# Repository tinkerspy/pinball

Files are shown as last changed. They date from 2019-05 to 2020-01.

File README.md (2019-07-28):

# Automaton Pinball

Pinball programming framework being built on a 1973 Williams OXO pinball machine.

- Modular cat5 cable connected architecture with just a single Teensy 3.2 mcu
- Three dimensional switch matrix with 5 x 8 x 8 = 320 switches
- Outputs controlled by addressable led strips (sk6812/ws2812b)
- Solenoids driven by optical mosfet switches
- Galvanic isolation between logical (5V) and power circuits (24V+)
- Event driven Automaton-framework based code

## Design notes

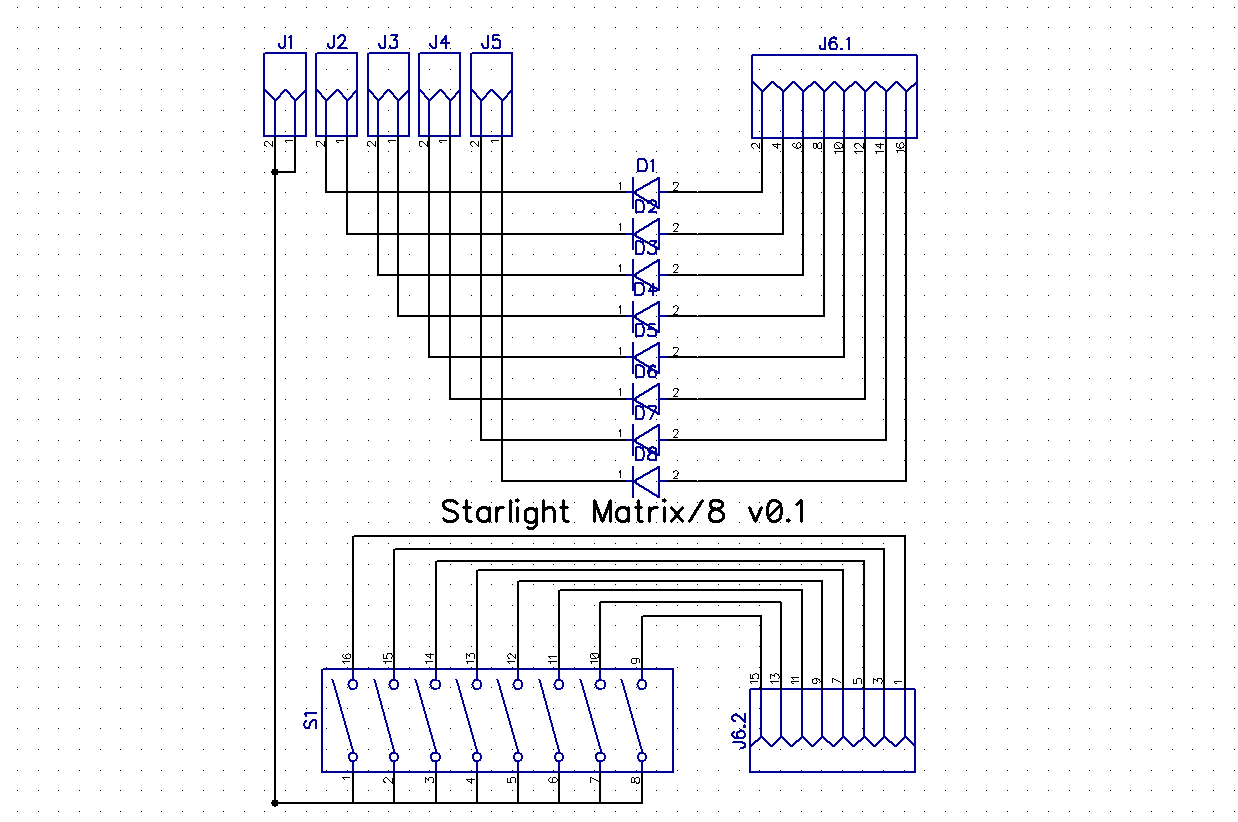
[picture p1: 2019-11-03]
diptrace/png/switchnodexl02-schematic.png

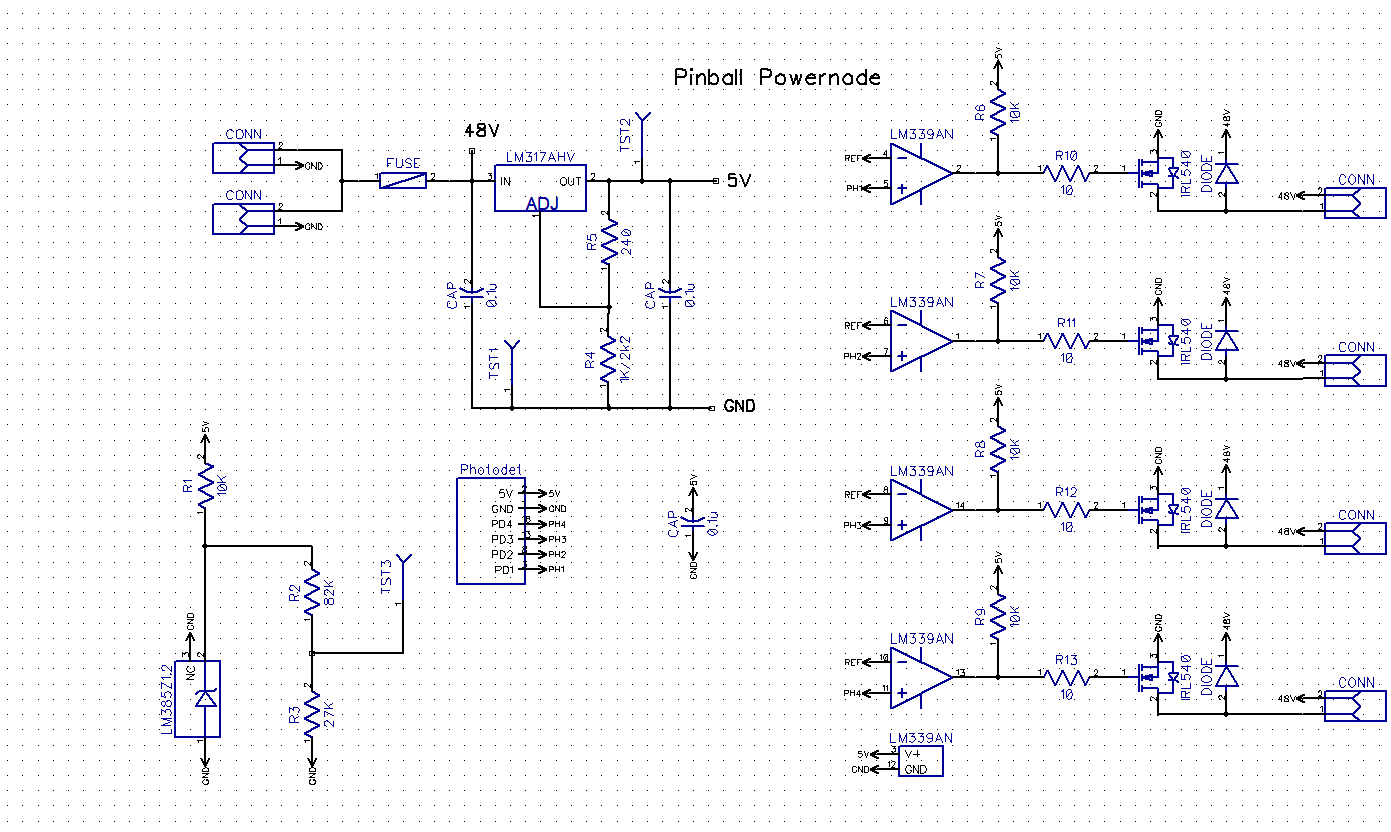
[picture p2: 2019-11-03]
diptrace/png/powernode03-schematic.png

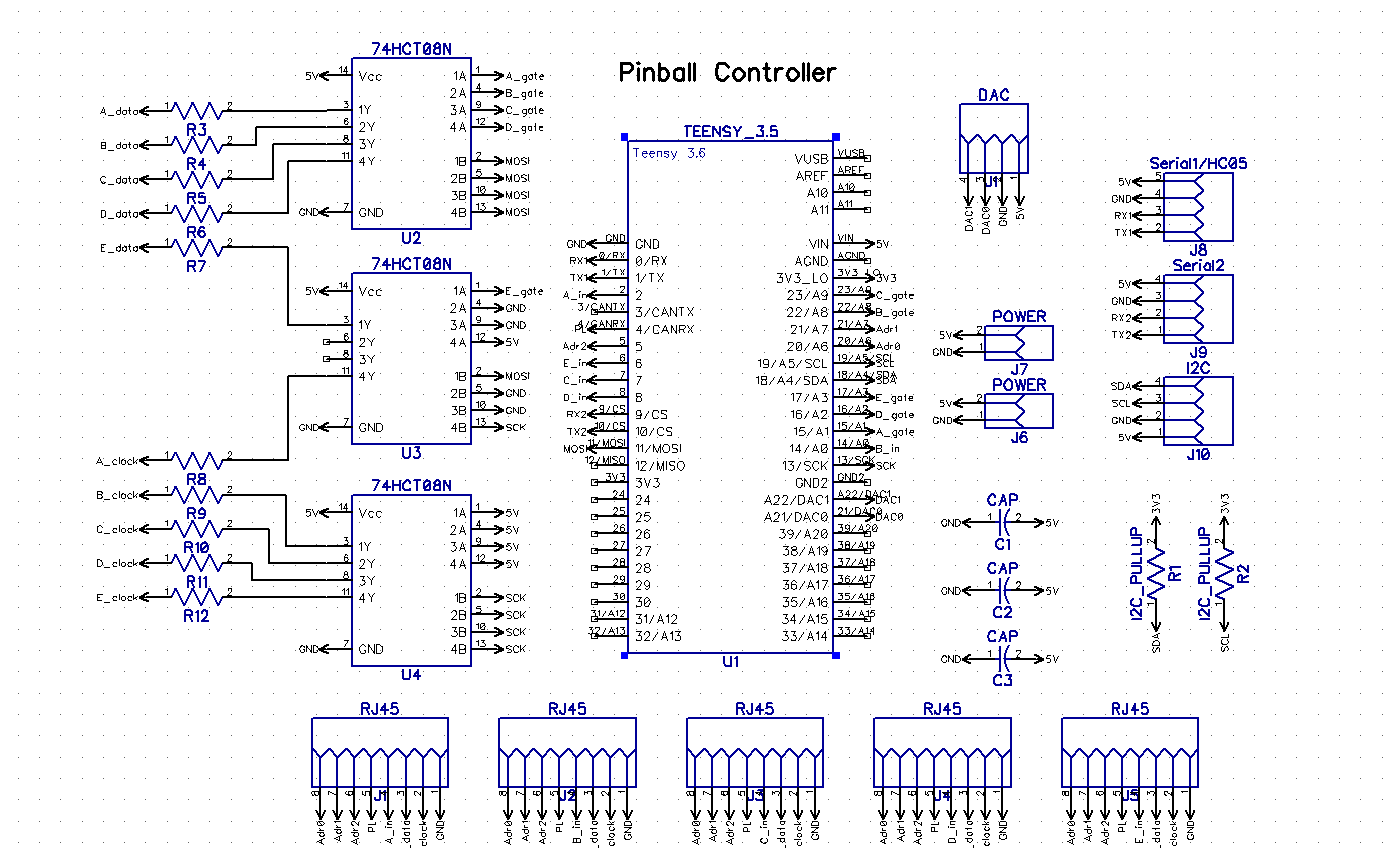
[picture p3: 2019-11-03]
diptrace/png/controller02-schematic.png

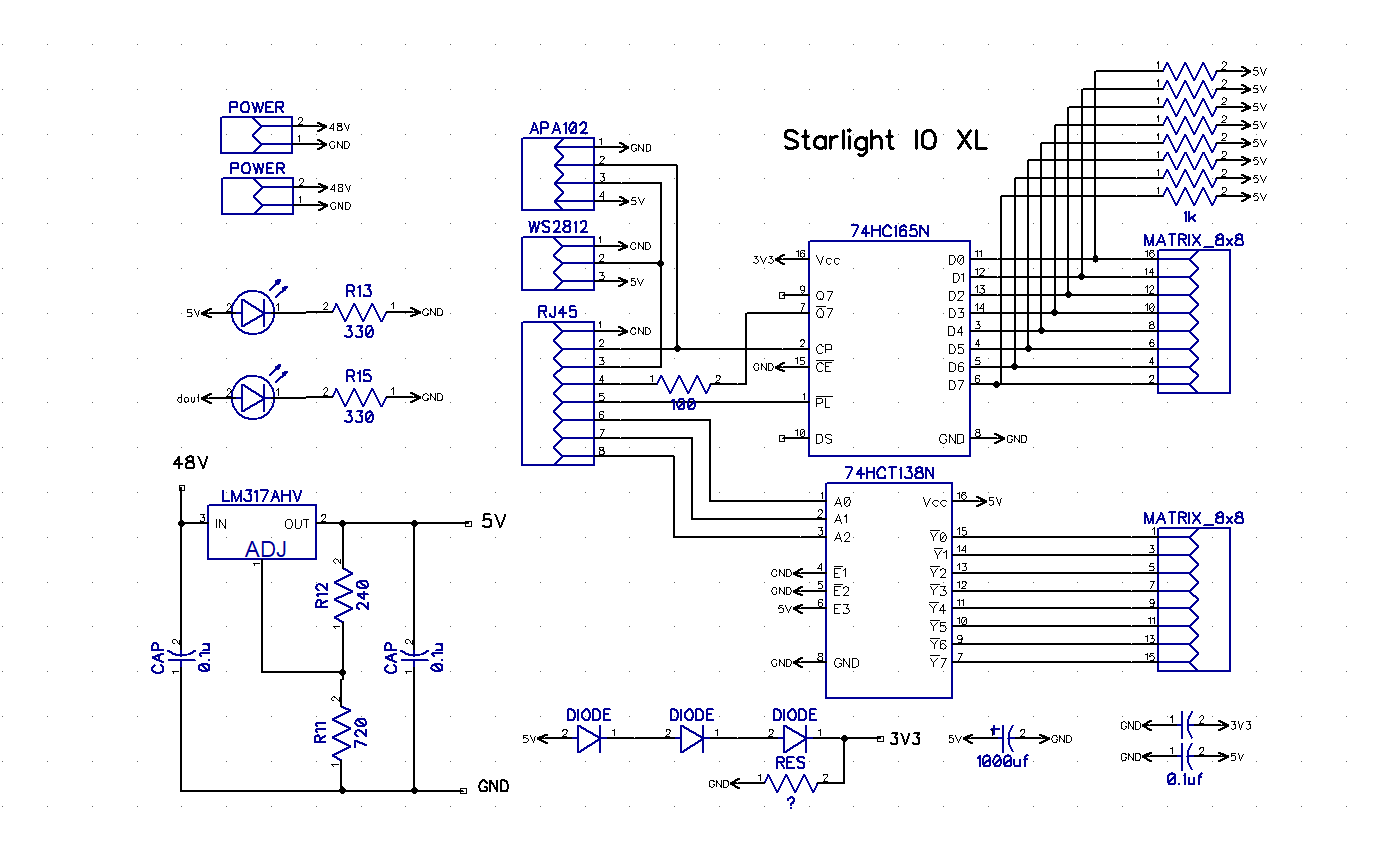
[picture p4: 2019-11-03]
diptrace/png/ionode03p-schematic.png

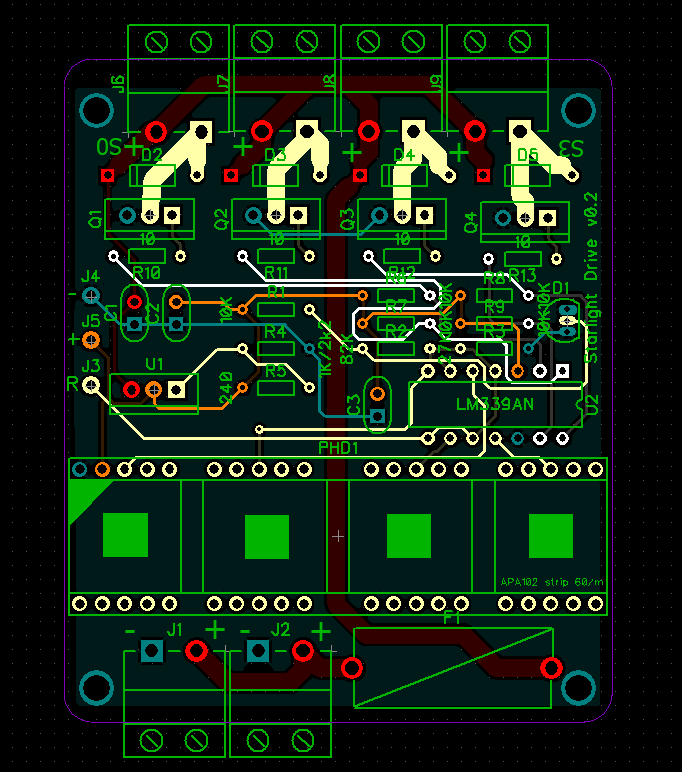
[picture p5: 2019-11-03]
diptrace/png/powernode03-pcb.png

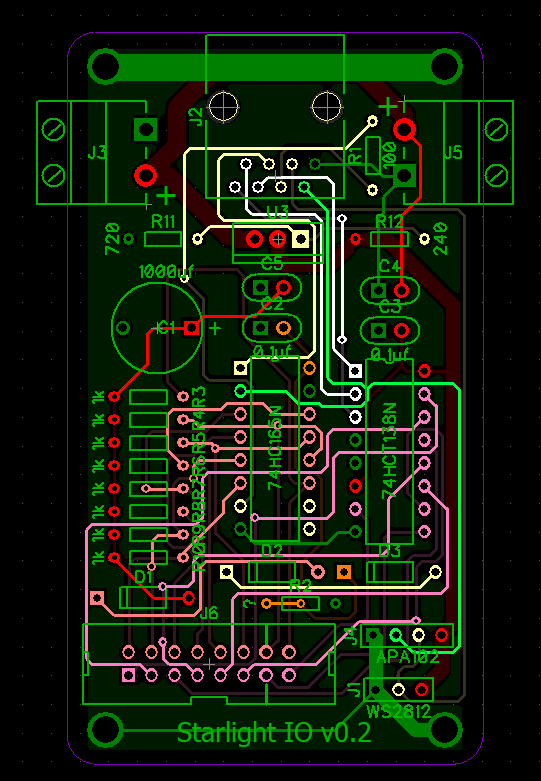
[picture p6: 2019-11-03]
diptrace/png/ionode03p-pcb.png

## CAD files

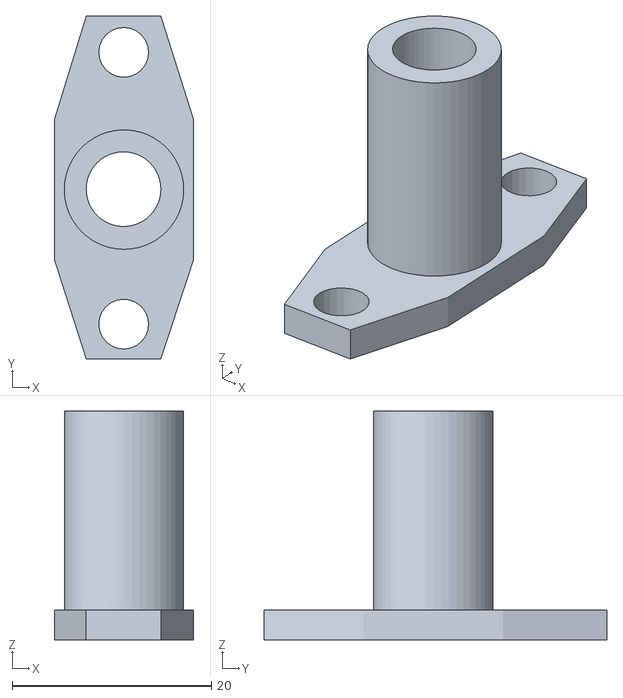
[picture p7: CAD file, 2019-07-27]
3d/pinball-led-insert.stl
14.0 x 34.4 x 23.0

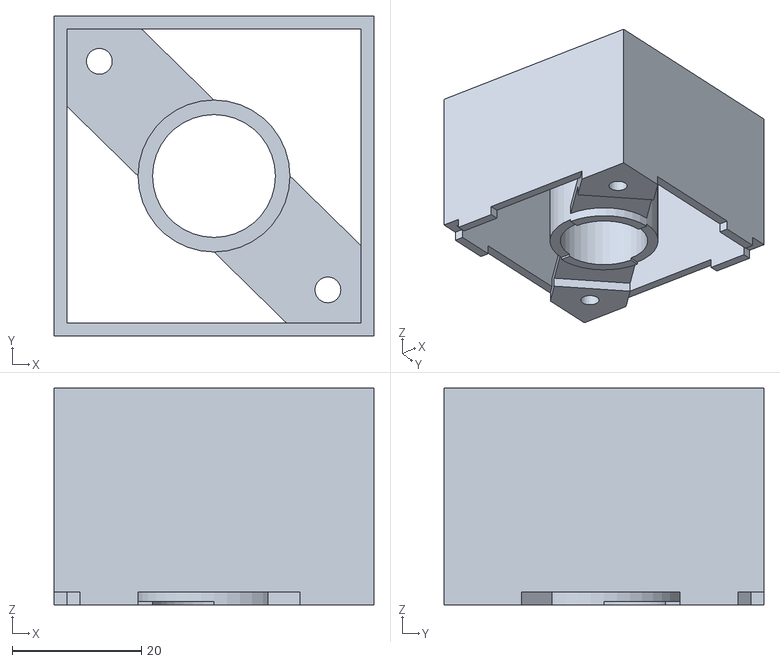
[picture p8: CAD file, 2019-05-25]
3d/oxo-insert.0.1b.stl
49.5 x 49.5 x 33.5

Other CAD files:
3d/oxo-insert.0.1.stl
3d/oxo-insert.0.1.skp
3d/oxo-insert.0.1b.skp
3d/pinball-led-insert.skp

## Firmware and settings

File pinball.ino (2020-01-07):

#include "Singularity.h"
#include "hardware.h"
#include "switches.h"
#include "leds.h"
#include "profiles.h"
#include "firmware_custom.h"
#include "freeram.hpp"

#define PRELOAD_CONFIG
#undef COMPILE_FW
#define NUMBER_OF_BALLS 3
#define NUMBER_OF_PLAYERS 4

using namespace standard_firmware;
using namespace custom_firmware; 

IO io;
Atm_led_matrix leds; 
Atm_switch_matrix playfield;
Library lib;

#include "CLI.h"

void setup() {
  delay( 100 );
  Serial.println( "Singularity Shell\r\ninit IO" );

  Serial1.begin( 9600 );
  cmd[0].begin( Serial, cmd_buffer[0], sizeof( cmd_buffer[0] ) )
    .list( cmdlist )
    .echo( true )
    .onCommand( cmd_callback, 0 );
    
  cmd[1].begin( Serial1, cmd_buffer[1], sizeof( cmd_buffer[1] ) ) 
    .list( cmdlist )
    .echo( true )
    .onCommand( cmd_callback, 1 );
    
  Serial1.println( "Singularity OS" );

  io.begin( pin_clock, pin_latch, addr, shift_inputs, gate );
  
  int32_t base_ram = FreeRam();

#ifdef COMPILE_FW
  Serial.println( "compile firmware from flash" ); //delay( 100 );
  lib.compile( "std_bumper", bumper_bytecode );
  lib.compile( "std_dual_target", dual_target_bytecode );
  lib.compile( "std_counter_em4d1w", counter_em4d1w_bytecode );
  lib.compile( "std_ledbank", ledbank_bytecode );
  lib.compile( "std_switchbank", switchbank_bytecode );
  lib.compile( "std_scalar", scalar_bytecode );
  lib.compile( "std_dual_kicker", dual_kicker_bytecode  );
  lib.compile( "std_dual_slingshot", dual_slingshot_bytecode  );
  lib.compile( "std_dual_combo", dual_combo_bytecode );
  lib.compile( "std_dual_flipper", dual_flipper_bytecode );

  lib.compile( "std_game", game_bytecode );
  lib.compile( "std_tictactoe", tictactoe_bytecode ); // phucked! it's just too big for loadintlist!!!
  lib.compile( "std_animation", animation_bytecode );
#else 
  Serial.println( "import firmware from flash" ); //delay( 100 );
  lib.import( "std_bumper", std_bumper_symbin, std_bumper_hexbin );
  lib.import( "std_dual_target", std_dual_target_symbin, std_dual_target_hexbin );
  lib.import( "std_counter_em4d1w", std_counter_em4d1w_symbin, std_counter_em4d1w_hexbin );
  lib.import( "std_ledbank", std_ledbank_symbin, std_ledbank_hexbin );
  lib.import( "std_switchbank", std_switchbank_symbin, std_switchbank_hexbin );
  lib.import( "std_scalar", std_scalar_symbin, std_scalar_hexbin );
  lib.import( "std_dual_kicker", std_dual_kicker_symbin, std_dual_kicker_hexbin  );
  lib.import( "std_dual_slingshot", std_dual_slingshot_symbin, std_dual_slingshot_hexbin  );
  lib.import( "std_dual_combo", std_dual_combo_symbin, std_dual_combo_hexbin );
  lib.import( "std_dual_flipper", std_dual_flipper_symbin, std_dual_flipper_hexbin );
  
  lib.import( "std_game", std_game_symbin, std_game_hexbin );
  lib.import( "std_tictactoe", std_tictactoe_symbin, std_tictactoe_hexbin );
  lib.import( "std_animation", std_animation_symbin, std_animation_hexbin );
#endif


#ifdef PRELOAD_CONFIG
  #include "load_config.h"
#endif

//  playfield.device( "kicker" ).trigger( IN_KICKER_PERSIST ); FIXME SOMEHOW!
  
  Serial.printf( "%.2f KBytes available, %.2f KBytes used for devices, %.2f Bytes free\r\n\r\n", 
        (float) base_ram / 1024, (float)( base_ram - FreeRam() ) / 1024, (float)( FreeRam() ) );

}

void loop() {
  automaton.run(); 
}

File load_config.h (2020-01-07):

  io.attach( 0, 3, new IO_Adafruit_NeoPixel( 53, pin_data, IO_Adafruit_NeoPixel::str2int( "neo_grbw" ) + IO_Adafruit_NeoPixel::str2int( "neo_khz800" ) ) );
  io.attach( 1, 1, new IO_Adafruit_NeoPixel( 12, pin_data, IO_Adafruit_NeoPixel::str2int( "neo_grbw" ) + IO_Adafruit_NeoPixel::str2int( "neo_khz800" ) ) );
  io.attach( 2, 1, new IO_Adafruit_NeoPixel( 36, pin_data, IO_Adafruit_NeoPixel::str2int( "neo_grbw" ) + IO_Adafruit_NeoPixel::str2int( "neo_khz800" ) ) );
  io.retrigger();
  io.show();

  leds.begin( io );
  playfield.begin( io, leds );

  leds.loadSymbols( led_symbols );
  leds.loadGroups( led_group_list  );

  playfield.loadSymbols( switch_symbols );
  playfield.loadGroups( switch_group_list );

  io.invert( playfield.findSymbol( "ball_enter" ) );

  Serial.println( "led profiles" ); //delay( 100 );

  //                                   T0,  L1,  T1,  L2  
  leds.profile( "led_kicker_l"     ,    0,   0,   0, 127 );
  leds.profile( "led_kicker_r"     ,    0,   0,   0, 127 );
  leds.profile( "led_target_grp"   ,    0,   0,   0, 127 );
  leds.profile( "led_uplane_grp"   ,    0,   0,   0, 127 );
  leds.profile( "led_bumper_a"     ,    0,   0,   0, 127 );
  leds.profile( "led_bumper_b"     ,    0,   0,   0, 127 );
  leds.profile( "led_bumper_c"     ,    0,   0,   0, 127 );
  leds.profile( "led_again0"       ,    0,   0,   0, 127 );
  leds.profile( "led_triple_bonus" ,    0,   0,   0, 127 );
  leds.profile( "led_extra"        ,    0,   0,   0, 127 );
  leds.profile( "led_headbox_grp"  ,    0,   0,   0, 255 );
  leds.profile( "led_oxo_grp"      ,    0,   0,   0, 127 );
  leds.profile( "coil_gi"          ,    0,   0,   0, 255 );
  leds.profile( "coil_sling_r"     ,    0, 255,  30,   0 );
  leds.profile( "coil_sling_l"     ,    0, 255,  30,   0 );
  leds.profile( "coil_flipper_l"   ,    0,   0,   0, 255 );
  leds.profile( "coil_flipper_r"   ,    0,   0,   0, 255 );
  leds.profile( "coil_kicker_r"    , 1000,  95,  30,   0 );
  leds.profile( "coil_kicker_l"    , 1000,  95,  30,   0 );
  leds.profile( "coil_save_gate"   ,    0,   0,   0, 255 );
  leds.profile( "coil_bumper_a"    ,    0, 255,  40,   0 );
  leds.profile( "coil_bumper_b"    ,    0, 255,  40,   0 );
  leds.profile( "coil_bumper_c"    ,    0, 255,  40,   0 );
  leds.profile( "coil_feeder"      ,    0, 127,  30,   0 );
  leds.profile( "coil_counter_grp" ,    0, 180,  20,   0 );
  leds.profile( "vled_counter0"    ,    0,   0,   0, 127 );
  leds.profile( "vled_counter1"    ,    0,   0,   0, 127 );
  leds.profile( "vled_counter2"    ,    0,   0,   0, 127 );
  leds.profile( "vled_counter3"    ,    0,   0,   0, 127 );
  leds.profile( "vled_collecting"  ,    0,   0,   0, 127 );
  leds.profile( "vled_5"           ,    0,   0,   0, 127 );
  leds.profile( "vled_6"           ,    0,   0,   0, 127 );
  leds.profile( "vled_7"           ,    0,   0,   0, 127 );
  
  Serial.println( "switch profiles" ); //delay( 100 );
  //                                    press,  rel,  thr,  sep
  playfield.profile( "switches"       ,   200,    0,    0,    0 );  // Default for switches
  playfield.profile( "multilane"      ,   200,  200,    0,    0 );
  playfield.profile( "sling_l"        ,     5,    0, 5000,    0 );  // Slingshots
  playfield.profile( "sling_r"        ,     5,    0, 5000,    0 );
  playfield.profile( "bumper_a"       ,     0,    0, 2000,    0 );  // Bumpers
  playfield.profile( "bumper_b"       ,     0,    0, 2000,    0 );
  playfield.profile( "bumper_c"       ,     0,    0, 2000,    0 );
  playfield.profile( "flipper"        ,     0,   10,    0,    0 );  // Flippers
  playfield.profile( "counter0"       ,     0,  200,    0,    0 );  // Counter sensors
  playfield.profile( "counter1"       ,     0,  200,    0,    0 );
  playfield.profile( "counter2"       ,     0,  200,    0,    0 );
  playfield.profile( "counter3"       ,     0,  200,    0,    0 );
  playfield.profile( "port_3x"        ,     5,    0, 5000,    0 );
  playfield.profile( "port_3o"        ,     5,    0, 5000,    0 );
  playfield.profile( "port_2x"        ,     5,    0, 5000,    0 );
  playfield.profile( "port_2o"        ,     5,    0, 5000,    0 );
  playfield.profile( "port_1x"        ,     5,    0, 5000,    0 );
  playfield.profile( "port_1o"        ,     5,    0, 5000,    0 );
  playfield.profile( "uplane_l"       ,     5,    0, 5000,    0 );
  playfield.profile( "uplane_r"       ,     5,    0, 5000,    0 );
  playfield.profile( "outlane"        ,     5,    0, 5000,    0 );
  playfield.profile( "inlane_l"       ,     5,    0, 5000,    0 );
  playfield.profile( "inlane_r"       ,     5,    0, 5000,    0 );
  playfield.profile( "ball_enter"     ,     5,    0, 5000,    0 );
  playfield.profile( "rollover"       ,     1,    0, 5000,    0 );
  playfield.profile( "target_a"       ,     2,    0,    0,    0 );
  playfield.profile( "target_b"       ,     2,    0,    0,    0 );
  playfield.profile( "target_c"       ,     2,    0,    0,    0 );
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

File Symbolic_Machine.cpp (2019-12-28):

#include "Symbolic_Machine.hpp"

void Symbolic_Machine::clearComments( char s[] ) {
  char* p = s;
  bool comment = 0;
  while ( *p != '\0' ) {
     if ( *p == '/' ) comment = 1;
     if ( *p == '\n' ) comment = 0;
     if ( comment ) *p = ' ';
     p++; 
  }
}

int16_t Symbolic_Machine::loadIntList( const symbolic_machine_table* symbols, const char src[], int16_t dst[], int16_t dict_size, int16_t dict_offset /* = 0 */, bool sparse_jumptable /* = false */ ) {
  char buf[2048];
  char *token;
  const char separator[] = ", \n\t\r";
  int16_t* pcode = dst + dict_size;
  if ( dst != NULL ) {
    for ( int16_t i = 0; i < dict_size; i++ ) {
      dst[i] = sparse_jumptable ? 0 : dict_size;
    }
  }
  while ( strlen( src ) > 0 ) {
    char* end_of_record = strchr( src, ';' );
    if ( end_of_record == NULL ) break;
    strncpy( buf, src, end_of_record - src );
    buf[end_of_record - src] = '\0';
/*
    Serial.print( ">>" );
    Serial.print( buf );
    Serial.println( "<<" );
    */
    clearComments( buf );
    /*
    Serial.print( ">>" );
    Serial.print( buf );
    Serial.println( "<<" );
    if ( sparse_jumptable ) delay( 100000000 ); // FIXME!!!
    */
    src += end_of_record - src + 1;
    token = strtok( buf, separator );
    int16_t i = findSymbol( symbols, token, -32768 ); 
    if ( strlen( token ) > 0 && i == -32768 ) Serial.printf( "Compile error: token '%s' not found\r\n", token );
    if ( dst == NULL ) {
      pcode++;
      pcode++;
    } else {  
      *pcode++ = -1; 
      *pcode++ = i;
      dst[i - dict_offset] = ( pcode - dst );
    }
    token = strtok(NULL, separator );
    while( token != NULL ) {
      int16_t i = findSymbol( symbols, token, -32768 ); 
      if ( strlen( token ) > 0 && i == -32768 ) Serial.printf( "Compile error: token '%s' not found\r\n", token );
      if ( dst == NULL ) {
        pcode++;
      } else {
        *pcode++ = i;        
      }
      token = strtok(NULL, separator );
    }
  }
  if ( dst == NULL ) {
    pcode += 2;
  } else {
    *pcode++ = -1; 
    *pcode++ = -1;     
  }
  return pcode - dst;
}


int16_t* Symbolic_Machine::compileList( const char src[], int16_t dict_size, int16_t dict_offset /* = 0 */ ) {
  int16_t data_size = loadIntList( symbols, src, NULL, dict_size, dict_offset );
  int16_t* pdata = (int16_t *) malloc( data_size * 2 );
  memset( pdata, 0, data_size * 2 );
  loadIntList( symbols, src, pdata, dict_size, dict_offset );
  /*
  for ( int16_t i = 0; i < data_size; i++ ) {
    Serial.printf( "%d: %d\n", i, pdata[i] );
  }
  */
  return pdata;
}


// Parses a string of \n separated symbol banks

Symbolic_Machine& Symbolic_Machine::loadSymbols( const char s[] ) {
  while ( *s != '\0' ) {
    s = loadSymbolString( s );
  }
  return *this; 
}

Symbolic_Machine& Symbolic_Machine::linkSymbols( symbolic_machine_table* sym ) {
  symbols = sym;    
  return *this; 
}

// Parses a string and stores the symbols in a bank added to the end of a linked list

// TODO: kan zonder buffer in two-pass: 1. bereken malloc lengte 2. kopieer karakters een voor een

const char* Symbolic_Machine::loadSymbolString( const char* s ) { 
  char buf[2048];
  char sep[] = " ,;";
  char* b = buf;
  int16_t char_cnt = 0;
  while ( *s != '\0' && *s != '\n' ) {
    while ( *s != '\0' && *s != '\n' && strchr( sep, *s ) != NULL ) {
      s++;      
    }
    while ( *s != '\0' && *s != '\n' && strchr( sep, *s ) == NULL ) {
      char_cnt++;
      *b++ = tolower( *s );
      s++;      
    }
    while ( *s != '\0' && *s != '\n' && strchr( sep, *s ) != NULL ) {
      s++;      
    }
    *b++ = '\0';
  }
  *b = '\0'; 
  s++;
  // Add new tables to the end of the linked list
  if ( char_cnt > 0 ) {
    symbolic_machine_table** p = &symbols;
    while ( *p != NULL ) p = &(*p)->next;
    *p = (symbolic_machine_table*) malloc( sizeof( symbolic_machine_table ) + ( b - buf ) + 1 );
    memcpy( (*p)->s, buf, ( b - buf ) + 1 );
    (*p)->next = NULL;
    (*p)->offset = 0;
  }
  return s;
}

// Returns the index of a symbol string in any of the banks
// If the argument string looks like a number return that number
// If the argument string is a single character return its ascii value

int16_t Symbolic_Machine::findSymbol( const char s[], int16_t def /* = 0 */ ) {
  symbolic_machine_table* p = symbols;
  if ( strlen( s ) == 0 ) return 0;
  if ( isdigit( s[0] ) || ( s[0] == '-' && isdigit( s[1] ) ) ) return atoi( s );   
  if ( strlen( s ) == 1 ) return s[0];
  while ( p != NULL ) {
    int16_t i = findSymbolString( s, p->s );
    if ( i >= 0 ) return i;
    p = p->offset > 0 ? (symbolic_machine_table *) ( (char*) p + sizeof( symbolic_machine_table ) + p->offset ) : p->next;
  }
  if ( def == 0 ) Serial.printf( "ERROR: Symbolic::findSymbol( %s ) failed\r\n", s );
  return def;
}

int16_t Symbolic_Machine::findSymbol( const symbolic_machine_table* symbols, const char s[], int16_t def /* = 0 */ ) {
  const symbolic_machine_table* p = symbols;
  if ( strlen( s ) == 0 ) return 0;
  if ( isdigit( s[0] ) || ( s[0] == '-' && isdigit( s[1] ) ) ) return atoi( s );   
  if ( strlen( s ) == 1 ) return s[0];
  while ( p != NULL ) {
    int16_t i = findSymbolString( s, p->s );
    if ( i >= 0 ) return i;
    p = p->offset > 0 ? (symbolic_machine_table *) ( (char*) p + sizeof( symbolic_machine_table ) + p->offset ) : p->next;
  }
  if ( def == 0 ) Serial.printf( "ERROR: Symbolic::findSymbol( %s ) failed\r\n", s );
  return def;
}

// Returns the n-th symbol in a bank or a NULL pointer if it does not exist

const char* Symbolic_Machine::findSymbol( int16_t idx, int8_t bank /* = 0 */, const char* def /* = NULL */ ) {
  symbolic_machine_table* p = symbols;
  uint8_t pcnt = 0;
  if ( idx < 0 ) {
    return def == NULL ? null_str : def;
  }  
  while ( p != NULL && pcnt < bank ) {
    p = p->offset > 0 ? (symbolic_machine_table *) ( (char*) p + sizeof( symbolic_machine_table ) + p->offset ) : p->next;
    pcnt++;
  }
  if ( p == NULL ) return def;
  uint8_t scnt = 0;
  char* s = p->s;
  while ( *s != '\0' && scnt < idx ) {
    s += strlen( s ) + 1;
    scnt++;
  }
  return *s == '\0' ? def : s;
}

// Returns number of symbols in a bank

int16_t Symbolic_Machine::countSymbols( int8_t bank /* = 0 */ ) {
  symbolic_machine_table* p = symbols;
  uint8_t pcnt = 0;
  while ( p != NULL && pcnt < bank ) {
    p = p->offset > 0 ? (symbolic_machine_table *) ( (char*) p + sizeof( symbolic_machine_table ) + p->offset ) : p->next;
    pcnt++;
  }
  if ( p == NULL ) return 0;
  uint8_t scnt = 0;
  char* s = p->s;
  while ( *s != '\0' ) {
    s += strlen( s ) + 1;
    scnt++;
  }
  return scnt;
}

// Find a string in a char array of null terminated strings (terminated by an empty string -- double \0 )
// Returns string index or -1 if not found
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

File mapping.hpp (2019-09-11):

#pragma once

/*
 * Aims:
 * - Minimal wiring
 * - Minimal I/O pins
 * - Minimal code
 * - Minimal latency
 */

uint8_t gate[5] = { 15, 22, 23, 16, 17 };
uint8_t shift_inputs[5] = { 2, 14, 7, 8, 6 };
uint8_t addr[3] = { 5, 21, 20 };

const int pin_data = 11;
const int pin_clock = 13;
const int pin_latch = 4;

// Led & coil profiles 

enum { 
  PROFILE_COIL, 
  PROFILE_LED, 
  PROFILE_FLIPPER, 
  PROFILE_KICKER, 
  PROFILE_FEEDER, 
  PROFILE_GATE, 
  PROFILE_BUMPER,
  PROFILE_GI,
  PROFILE_OXO,
  PROFILE_COUNTER,
  PROFILE_BRIGHT,
};

/* 
 *  - ID Profile ID
 *  - T0 Wait time before led on
 *  - L1 Initial led level (0-255)
 *  - T1 Initial period
 *  - L2 Hold level
 */ 

const int16_t profile_definition[] = {
/*                    T0   L1  T1   L2  */ 
  PROFILE_COIL,        0, 255, 30,   0, -1,
  PROFILE_LED,         0,   0,  0, 127, -1,
  PROFILE_FLIPPER,     0,   0,  0, 255, -1,
  PROFILE_KICKER,   1000,  95, 30,   0, -1,
  PROFILE_GATE,        0,   0,  0, 255, -1,
  PROFILE_BUMPER,      0, 255, 30,   0, -1,
  PROFILE_FEEDER,   1000, 127, 30,   0, -1,
  PROFILE_GI,          0,   0,  0, 255, -1,
  PROFILE_OXO,         0,   0,  0, 127, -1,
  PROFILE_COUNTER,     0, 255, 30,   0, -1,
  PROFILE_BRIGHT,      0,   0,  0, 255, -1,
  -1,  
};

// Coils & leds (outputs) /////////////////////////////////////////////////////////////////////////////////

enum { 
/* coil node 1 */
  /* a */  COIL_SAVE_GATE, 
  /* b */  COIL_FLIPPER_R,
  /* c */  COIL_BALL_FEEDER,
  /* d */  COIL_SLING_R,
/* coil node 2 */
  /* e */  COIL_SLING_L,  
  /* f */  COIL_FLIPPER_L,
  /* g */  COIL_KICKER_R,
  /* h */  COIL_KICKER_L,
/* coil node 3 */
  /* i */  COIL_BUMPER_A, 
  /* j */  COIL_BUMPER_B,
  /* k */  COIL_BUMPER_C,
  /* l */  COIL_GI,
/* playfield leds */  
  /* m */  LED_TARGET_A,
  /* n */  LED_BUMPER_C,
  /* o */  LED_BUMPER_A,
  /* p */  LED_BUMPER_B,
  /* q */  LED_TARGET_B,
  /* r */  LED_UP_LANE_R,
  /* s */  LED_KICKER_R,
  /* t */  LED_AGAIN0,
  /* u */  LED_TRIPLE_BONUS,
  /* v */  LED_EXTRA, 
  /* w */  LED_KICKER_L,
  /* x */  LED_UP_LANE_L,  
  
/* OXO leds: 27 + 2 */
  LED_OXO_3A, LED_OXO_3B, LED_OXO_3C, // OXO leds in physical order
  LED_OXO_6A, LED_OXO_6B, LED_OXO_6C,
  LED_OXO_2A, LED_OXO_2B, LED_OXO_2C,
  LED_OXO_1A, LED_OXO_1B, LED_OXO_1C,
  LED_OXO_5A, LED_OXO_5B, LED_OXO_5C,
  LED_OXO_9A, LED_OXO_9B, LED_OXO_9C,  
  LED_OXO_8A, LED_OXO_8B, LED_OXO_8C,
  LED_OXO_4A, LED_OXO_4B, LED_OXO_4C, 
  LED_OXO_7A, LED_OXO_7B, LED_OXO_7C,
  LED_OXO_O, LED_OXO_X, // FIXME these are the other way around!

  COIL_CHIME0,  // Dummy entries for led strip on P2 (cabinet)
  COIL_CHIME1,
  COIL_CHIME2,
  COIL_KNOCKER,
  
  COIL_COUNTER0_10, COIL_COUNTER0_100, COIL_COUNTER0_1K, COIL_COUNTER0_10K, // Strip on P3 (headbox)
  COIL_COUNTER2_10, COIL_COUNTER2_100, COIL_COUNTER2_1K, COIL_COUNTER2_10K,
  COIL_COUNTER3_10K, COIL_COUNTER3_1K, COIL_COUNTER3_100, COIL_COUNTER3_10,
  COIL_COUNTER1_10K, COIL_COUNTER1_1K, COIL_COUNTER1_100, COIL_COUNTER1_10,
  LED_UP1,
  LED_OXO_ANI2, LED_OXO_ANI1, LED_OXO_ANI0,
  LED_UP0, LED_UP2, LED_UP3,
  LED_TILT,
  LED_PLAY4, LED_PLAY3, LED_PLAY2, LED_PLAY1,
  LED_AGAIN2, LED_AGAIN1,
  LED_BALL3, LED_BALL5, LED_BALL2, LED_BALL4, LED_BALL1,
  LED_GAME_OVER,
  
  /* Virtual LED groups - up to 32 - are declared after physical leds */
  LED_KICKER_GRP,
  LED_UP_LANE_GRP,  
  LED_OXO_GRP,
  LED_OXO_CELLS,
  LED_BUMPER_GRP,
  LED_FLASHER_GRP,
  LED_TARGET_GRP,
  COIL_COUNTER0_GRP,
  COIL_COUNTER1_GRP,
  COIL_COUNTER2_GRP,
  COIL_COUNTER3_GRP,
  LED_UP_GRP,
  LED_PLAY_GRP,
  LED_BALL_GRP,
  LED_AGAIN_GRP,
  LED_OXO_ANI_GRP,
  LED_HEADBOX_GRP,
  LED_OXO_XXX,
};

// Switches (inputs) ///////////////////////////////////////////////////////////////////////////////////

enum { 
/* Dummy, switches start at 1 and go up to 320 */  
  NULL_SW,
/* Physical switches */  
  TARGET_B, // MX10
  PORT_3X,
  PORT_3O,
  PORT_2X,
  PORT_2O,
  PORT_1X,
  PORT_1O,
  TARGET_A,
  KICKER_L, // MX11
  UP_LANE_L,
  BUMPER_A,
  BUMPER_C,
  KICKER_R,
  BUMPER_B,
  UP_LANE_R,
  TARGET_C,
  OUT_LANE, // MX12
  IN_LANE_L,
  SLING_L,
  SLING_R,
  ROLLOVER,
  IN_LANE_R,
  BALL_ENTER,
  BALL_EXIT,
  TILT_PEND, // MX21
  TILT_RAMP,
  SWITCH213,
  FLIPPER_L,
  FLIPPER_R,
  SWITCH216,
  SWITCH217,
  FRONTBTN,
  COUNTER2,// MX31
  COUNTER0, 
  SWITCH313,
  SWITCH314,
  SWITCH315,
  SWITCH316,
  COUNTER1,
  COUNTER3,
  
/* Virtual switches (for elements without physical switches) */  
  SAVE_GATE,
  CHIME0,
  CHIME1,
  CHIME2,
};

/* group_map - Defines virtual LEDs (groups of leds) /////////////////////////////////////////////////////////////////////////
 *  
 * Record starts with the group ID followed by the elements, ended by a -1 entry.
 * The last record in the list is followed by a second -1 entry to signal end of list 
 * 
 * Leds and switches can be mixed as long as you make sure no Atm_led_scheduler actions
 * are performed on the group.
 */
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

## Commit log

2018-06-17 Removed matrix etc.
    Atm_apa102 now ignores ledno == -1
    Default pulse_time = -1
2018-06-19 Prepared code for splitting up led strips
2018-06-20 led 27/28 used as selector
2018-06-20 Removed matched, replaced with MATCH state
    [pinball.ino]
2018-06-22 OXO physical led order
2018-06-24 smart_bot try prevent forks
    [pinball.ino]
2018-06-27 pcb updates: added i2c pullups and direct io diodes
2018-07-19 Atm_apa102 now works on UNO, but not on Teensy!
    This version is broken, figure out why previous version works...
    [pinball.ino]
2018-07-20 SMD coil driver
2018-12-01 Again from schematic
2018-12-03 PCB changes
2018-12-05 Added Atm_strip concept (virtual led strip)
2018-12-23 Pcb changes: switchnode 02
2018-12-26 Fixed board outlines, made ionode v3v compatible
2018-12-26 Cleaned up old pcb versions
2018-12-29 Added pin 13 sharing between SPI & MX clock output
2018-12-31 PCB stuff
2019-01-02 Removed pulldown resistors
    Use Teensy 3.x INPUT_PULLDOWN mode in software.
2019-01-06 PCB fixes
2019-01-14 Preparing the pcbs, ionode xl
2019-01-19 PCBs sent to fab
2019-01-20 Added drill files
2019-03-02 Added led strip support to IO
    - Logical led addressing
    - Intelligent updates
2019-03-03 Added Atm_led_scheduler
    Handles automatic led timing & pulses.
    Profile based
2019-03-04 Everything fits
    - switchcodes more economical 1..48
    - led profiles work
    - cleaned up
2019-03-05 Cleanup, fixes
    state() didn't work for initialization
    Back to Atm_element::initialized
    Changed magic nos to constants
    [io.cpp, io.hpp]
2019-03-14 Basic playing works
    Stil to fix:
    global debouncing
    [Atm_led_scheduler.cpp, Atm_playfield.cpp, io.cpp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]
2019-03-30 New PCB order (ionodexl03p & powernode03)
2019-04-08 merged ledclass into repo
2019-05-05 autoKick, pulse, idle() added to element
    Elements ignore EVT_RELEASE by default, re-activate (for flippers) by specifying elm->pulse( false );
    [Atm_led_scheduler.cpp, Atm_playfield.cpp, mapping.hpp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]
2019-05-11 Fix hanging flippers, adjust pwms
    [Atm_led_scheduler.cpp, pinball.ino]
2019-05-18 Fixed debounce handling
    Flipper got stuck when triggered to fast.
    Solution: Call io.cancel() when debouncing
    [Atm_led_scheduler.cpp, Atm_playfield.cpp, io.cpp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]
2019-05-18 debounec & retrigger combined, renamed stuff, fixed idle()
    [Atm_playfield.cpp, io.cpp, io.hpp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]
2019-05-19 Element always checks led, created oxo light chamber insert
    [oxo-insert.0.1.skp, oxo-insert.0.1.stl]
2019-05-25 OXO insert working mostly
    Missing: Special on full
    [oxo-insert.0.1.skp, oxo-insert.0.1.stl, oxo-insert.0.1b.skp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]
2019-05-25 Oxo fixed
    EVT_FULL removed
    [mapping.hpp, pinball.ino]
2019-05-25 Fixed OXO led mapping
    [mapping.hpp, pinball.ino]
2019-05-26 Update led strip immediately on initialization
2019-05-30 Schematic: Added resistor values per mosfet type
2019-06-09 Set default switchMap( 8,8,8,8,8 );
2019-06-10 Added group() method to re-use infor from led_group_map
2019-06-10 Off by one error in group()
    [Atm_led_scheduler.cpp, pinball.ino]
2019-06-14 Renamed spare switches
2019-06-20 Element arg is now playfield, added leds.onWatch()
2019-06-23 New led() object replaces watch()
    [Atm_playfield.cpp, mapping.hpp, pinball.ino]
2019-06-28 Counter sensor oversampling (untested)
2019-06-29 Counter problem seems fixed, oversampling removed again
    [mapping.hpp, pinball.ino]
2019-06-29 Revert "Basic game loop works"
    This reverts commit 7dc964e4f1a051c596db7c25e4d17c108299ea59.
    [mapping.hpp, pinball.ino]
2019-06-29 Revert "Counter problem seems fixed, oversampling removed again"
    This reverts commit ea52379e3c226803ff8001ec581061cd92f6a4e1.
    [mapping.hpp, pinball.ino]
2019-06-29 Revert "Counter sensor oversampling (untested)"
    This reverts commit 6d5978494cdae3c9bb20cdeb97ba7207d53fbc60.
    [pinball.ino]
2019-08-14 Headbox leds working
2019-08-16 Added atm_score + bugfix
    Bug caused counter to freeze after '!touched' stopped a reset. Fixed by delaying ressetting variable state change.
    [io.cpp, pinball.ino]
2019-08-18 Two bugs fixed
    Ball dead after 0 bonus ball
    Up2 & Up3 mixed up
    [mapping.hpp, pinball.ino]
2019-08-20 Bugfix sensor_switch
2019-08-28 Knocker and 3d
    [oxo-cap-holder1.skp, oxo-cap-holder1.stl, oxo-cap-holder2.skp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]
2019-09-07 Peparation for io port filtering
2019-09-08 led_mapper arrays
2019-09-09 Fixes led mapping
2019-09-10 Matching integrated in device script
2019-09-11 Global counter, separate devices.h
2019-09-11 Basic led_device is working
2019-09-11 Led device gets playfield as an argument
2019-09-13 Working led device
2019-09-13 Cleanups, expanded device to max 16 outputs
2019-09-13 OXO needs no switches
2019-09-14 OXO & multilane devices are working
2019-09-14 Device factory prepared, waiting for switch groups
2019-09-14 Reorganized devices, added single switch
2019-09-14 microcode bug: oxo jumped 4 places instead of 2
    [pinball.ino]
2019-09-14 Switch group preps
2019-09-15 Switch groups & switch binding work?
    [Atm_playfield.cpp, io.cpp, pinball.ino]
2019-09-15 Playfield factory kind of works
    - OXO doesn't generate output (bonus)
    [Atm_playfield.cpp, io.cpp, pinball.ino]
2019-09-16 Wrestling the kicker
    Crashes the game now
    [Atm_playfield.cpp, io.cpp, io.hpp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]
2019-09-16 Bugfix by adding memset()
    [Atm_playfield.cpp, pinball.ino]
2019-09-16 Added target & bumper devices (untested)
2019-09-17 ledbank changes
2019-09-18 Targets work, GI switch (ledbank) does not...
2019-09-18 ledbank firmware, comma missing, fixed + warning
    [Atm_playfield.cpp, pinball.ino]
2019-09-18 Dropped Atm_oxo_field, device init change
    A device only initializes when a firware image is supplied
2019-09-19 Forgot to extend group table (catch error???)
    [Atm_playfield.cpp, pinball.ino]
2019-09-20 Lower switch collection
2019-09-20 Fully replaced elements with devices
    [Atm_playfield.cpp, pinball.ino]
2019-09-20 Digits in one device
2019-09-20 Revert "BLOCK -> FREEZE"
    This reverts commit 448c0f06e5aa6043876aa2ddd0fd6f5b8ecd3ee7.
    [pinball.ino]
2019-09-21 Bug in oxo device
    [pinball.ino]
2019-09-21 Scalar device works
2019-09-21 Added device chaining (untested)
2019-09-22 Chain-enabled Atm_em_counter (untested)
2019-09-22 Object chaining works, Atm_score dropped
2019-09-22 state() now always returns the sum of all device states in a chain
2019-09-22 Added dual core struct to devices (untested)
2019-09-23 Renamed some leds/groups
2019-09-23 Counter device reset (untested)
    [Atm_playfield.cpp, pinball.ino]
2019-09-24 Device based counters (untested)
2019-09-24 Reset runs, but result wrong
    [Atm_playfield.cpp, pinball.ino]
2019-09-25 RESET2 werkt, behalve vanaf xYYYx waar een van de Y = 9
    Het gaat om de initiele stand van de sensor wire.
    [pinball.ino]
2019-09-25 Disabled chaining for switch events & added retrigger for primary switch
2019-09-26 Cleanup & device-ified game_over
2019-09-26 Problems counter due to spurious switch releases?
    [Atm_device.cpp, Atm_playfield.cpp, pinball.ino]
2019-09-26 Debounce suspected, burning coil
    [pinball.ino]
2019-09-29 Debounce integration - still buggy
    [Atm_playfield.cpp, io.cpp, io.hpp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]
2019-10-01 Simplified flipper device
2019-10-02 Feeder fixed, seems stable
    [Atm_switch_matrix.cpp, io.cpp, pinball.ino]
2019-10-02 Compressed switchgroups work
2019-10-05 Led group conversie klaar
2019-10-05 Group handling bug fixed (off-by-one)
    [Atm_led_matrix.cpp, pinball.ino]
2019-10-06 Off by one bug in Atm_switch_matrix::device()
    [Atm_device.cpp, Atm_switch_matrix.cpp, pinball.ino]
2019-10-06 Added option to disable trace...
2019-10-06 Implemented Atm_device switches bitmap
    Automatically keeps state for the connected switches.
2019-10-06 Individual IO tracing for leds/switches
2019-10-07 Symbolic basic sample code
2019-10-07 Device::onEvent() now resolves device ids
    [Atm_device.cpp, pinball.ino]
2019-10-07 Bugfix device.chain()
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2019-10-09 Add pin toggles for pins 9, 10 & 18
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2019-10-12 State machine based throttle code
2019-10-12 Debouncing works, partial led refresh works well
    -
2019-10-12 Staggered counter reset is weird!
    [pinball.ino]
2019-10-13 Implemented execution counter in formware, added 4 virtual leds to cabinet
2019-10-13 Virtual leds: playing, counters dirty, collecting
2019-10-13 Mock game device call
2019-10-14 Dual_combo fix for sticky upper Special light
    [pinball.ino]
2019-10-14 Added SD card reader code
    [oxo.cfg]
2019-10-14 Dropped 2 led groups, sing0000.cfg
    [sing0000.cfg]
2019-10-15 Added [chains] section
    [sing0000.cfg]
2019-10-18 Separation filter added, profiles updated (untested)
2019-10-19 Opcode changes, game bytecode
    [sing0000.cfg]
2019-10-19 Game device werkt tot aan de game core, feeder werkt niet
2019-10-19 Game device begint te werken
2019-10-20 Game device basically working
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2019-10-23 Device symbol table loading in linked list
2019-10-25 Devices, leds & playfield are now Symbolic Machines
2019-10-26 Library kind of works, reverse symbol order
    [Atm_device.cpp, Atm_led_matrix.cpp, Atm_my_command.cpp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]
2019-10-27 Library symbols reversed: in-out-arg-reg
    [pinball.ino]
2019-10-28 Added lo (leds on list)
2019-10-28 Converted ledbank & counter
2019-10-29 device() & onEvent() methods now symbol aware
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2019-10-30 Problem with playfield links!
    [Atm_device.cpp, Atm_switch_matrix.cpp, Atm_switch_matrix.hpp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]
2019-10-31 Led & switch lists in ascii
2019-11-02 Negative value for separation makes switch ignored
2019-11-02 Led groups work, switch groups crash
    [Atm_led_matrix.cpp, Atm_switch_matrix.cpp, Atm_switch_matrix.hpp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]
2019-11-03 Diptrace png files added
    [sing0000.cfg]
2019-11-10 Event bitmaps & fixed 'info' cmd
    [Atm_device.cpp, CLI.h, Symbolic_Machine.cpp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]
2019-11-10 Game device works with event bitmap
2019-11-12 Mistook a blown fuse for a software problem
    [Atm_device.cpp, pinball.ino]
2019-11-16 First reset phases work
    [Atm_device.cpp, CLI.h, pinball.ino]
2019-11-16 Single thread counter reset works!
    [Atm_device.cpp, pinball.ino]
2019-11-17 DDC dump device code
2019-11-23 Added timeout for counter reset
    [Atm_device.cpp]
2019-11-23 All reset pulses via sub_pulse
    [pinball.ino]
2019-11-25 Some fixes
    [sing0000.cfg]
2019-11-28 DEVICE, LINK & CHAIN commands implemented (nonop)
2019-11-30 Fixed Atm_my_command, added echo & flow control
    [Atm_device.cpp, Atm_my_command.cpp, CLI.h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]
2019-12-02 Serial scripting works except for attach & fw
    [sing0000.cfg]
2019-12-28 Many things
    - Fixed off-by-one bug that messsed up 'info counter3'
    - attach command
    - moved attach to config
    [sing0000.cfg]
2019-12-28 Several changes
    - Removed persistence opcodes from all devices
    - loadIntList increased buffer 1024 -> 2048 (oxo was too big)
    [sing0000.cfg]
2019-12-28 Dedicated slingshot firmware, added playfield enabled checks
    [sing0000.cfg]
2019-12-29 Flipper release fixed
    [sing0000.cfg]
